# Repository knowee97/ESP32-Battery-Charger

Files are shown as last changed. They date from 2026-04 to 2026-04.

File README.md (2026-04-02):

# ESP32-Battery-Charger
4-layer PCB design featuring the **ESP32-C3-MINI-1** RISC-V SoC with integrated Li-Po battery management.
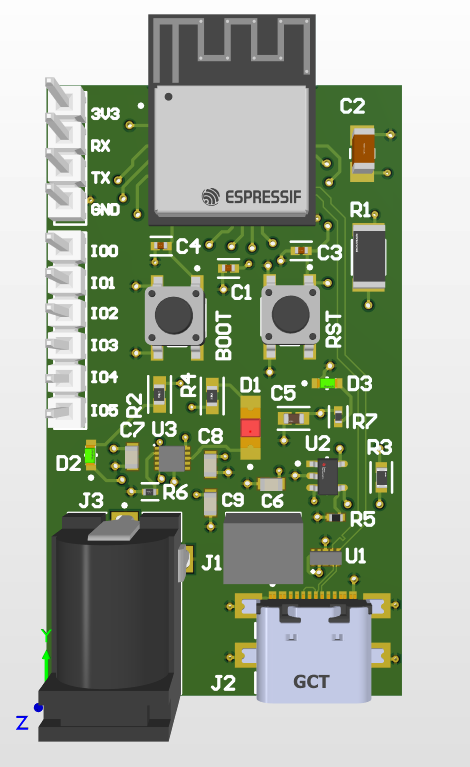
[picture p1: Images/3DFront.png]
ESP32-C3 PCB Render


## 🛠 Technical Specifications
* **Processor**: ESP32-C3-MINI-1 (RISC-V Single-Core, Wi-Fi/Bluetooth LE).
* **Layer Stackup**: 4-Layer (Signal-GND-PWR-Signal) for optimized EMI and Signal Integrity.
* **Power System**: 
    * Integrated Li-Ion Linear Charger with $500\text{mA}$ regulation.
    * USB-C Input with ESD protection and Schottky diode power-path management.
    * Dedicated **CHG** status LED tied to the charging IC.
* **High-Speed Routing**: $90\Omega$ impedance-matched differential pairs for **USB 2.0** data lines.

## 📐 Design & Layout Highlights
* **RF Optimization**: 
    * Implemented a strict 15mm antenna keep-out zone as per the Espressif datasheet.
    * Utilized ground stitching vias to create a low-impedance return path and reduce noise.
* **Thermal Management**: 
    * Designed a $3\times3$ thermal via array on the ESP32 center **EPAD** to dissipate heat into internal ground planes.
* **Manufacturing (DFM)**: 
    * Successfully resolved 50+ Design Rule Violations using targeted clearance exceptions.
    * Maintained 6mil trace/space clearance in high-density areas.

## 🏁 Design Rule Check (DRC)
* **Status**: 0 Errors / 0 Warnings.
* **Custom Rules**: 
    * Implemented `InComponent` queries to allow 1.4mil solder mask slivers on the ESP32 thermal pads while maintaining 10mil global safety clearances.

## 📁 Repository Structure
* `/Hardware`: Altium Designer project files and 3D STEP model.
* `/Manufacturing`: Production-ready Gerber and NC Drill files.
* `/Docs`: Schematic PDF and Bill of Materials (BOM).

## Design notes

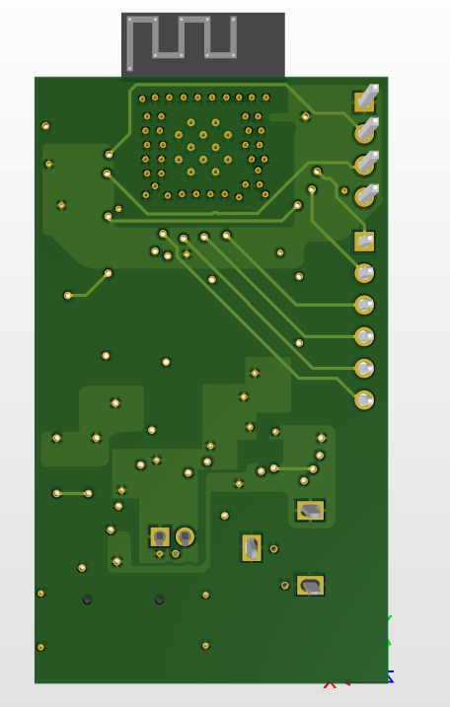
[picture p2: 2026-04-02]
Images/3DBack.png

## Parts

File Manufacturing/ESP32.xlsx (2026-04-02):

Comment | Description | Designator | Footprint | LibRef | Quantity
BOOT | TACT 4.5 X 4.5, 3.8 MM H, 1.8N, | BOOT | FP-PTS647SM38SMTR2LFS-MFG | CMP-10040-000031-1 | 1
HMK105B7103MVHFE | None | C1, C3, C4 | FP-0402-L_1_0_0_05-W_0_5-IPC_A | CMP-14477-001757-2 | 3
LMK316AB7106ML-T | None | C2 | FP-1206-L_3_2_0_2-W_1_6_0-IPC_A | CMP-14477-003406-2 | 1
GRM188Z71A106KA73J | Chip Multilayer Ceramic Capacitors for General Purpose, 0603, 10uF, X7R, 15%, 10%, 10V | C5 | FP-GRM188-0_2-IPC_B | CMP-06035-020296-1 | 1
C0603C105K4RACTU |  | C6, C7, C8, C9 | CAPC1608X90X35LL15T15 | CMP-2006-02298-2 | 4
LTST-C230EKT | LED RED CLEAR CHIP SMD | D1 | FP-LTST-C230EKT-MFG | CMP-22017-000030-1 | 1
APT1608ZGCK | LED GREEN CLEAR CHIP SMD | D2, D3 | FP-APT1608ZGCK-MFG | CMP-44529-000024-1 | 2
B2B-PH-K-S(LF)(SN) | Male Header, Pitch 2 mm, 1 x 2 Position, Height 6 mm, Tail Length 3.4 mm, -25 to 85 degC, RoHS, Bulk | J1 | JST-B2B-PH-K-S_V | CMP-2000-05162-1 | 1
USB4110-GF-A | CONN USB 2.0 TYPE-C R/A SMT | J2 | FP-USB4110-GF-A-MFG | CMP-245163-000002-1 | 1
PJ-102BH | Through Hole Right Angle DC Power Jack, 5 A, 2.5 mm Center Pin, 3 Position, -25 to 85 degC, RoHS, Bulk | J3 | CUI-PJ-102BH_V | CMP-2000-06901-1 | 1
ESP32-C3-MINI-1-N4 | Multiprotocol Modules SMD module, ESP32-C3FN4, PCB antenna, -40 C +85 C | MD1 | FP-ESP32-C3-MINI-1-N4-MFG | CMP-10700-116589975-1 | 1
TSW-104-08-G-S | 0.025" SQ Post Header, Through-hole, Vertical, -55 to 125 degC, 2.54 mm Pitch, 4-Pin, Male, RoHS | P1 | SMTC-TSW-104-08-X-S | CMP-1024-00357-1 | 1
TSW-106-23-G-S | 0.025" SQ Post Header, Through-hole, Vertical, -55 to 125 degC, 2.54 mm Pitch, 6-Pin, Male, RoHS | P2 | SMTC-TSW-106-23-X-S | CMP-1024-00396-1 | 1
CR2010-JW-103ELF | Thick Film Chip Resistors 2010 10kΩ 0.5W 5% 200ppm/°C | R1 | FP-CR2010-IPC_C | CMP-07231-003456-1 | 1
RN73R1JTTD1501B25 | 1.5kΩ ±0.1% 0.1W, 1/10W Chip Resistor 0603 (1608 Metric) Moisture Resistant Thin Film | R2, R4 | FP-RN73R1J-IPC_A | CMP-04015-030520-1 | 2
AT0603BRD0740KL | Thin Film Chip Resistors Automotive Grade 40kΩ 0.1% 25ppm/°C 0603 | R3 | FP-AT0603-IPC_B | CMP-03412-038922-1 | 1
ERJ-2RKF2003X | Chip Resistor, 200 KOhm, +/- 1%, 100 mW, -55 to 155 degC, 0402 (1005 Metric), RoHS, Tape and Reel | R5 | RESC1005X40X25NL05T05 | CMP-1011-00768-4 | 1
CRGCQ0402J1K0 | CRGCQ 0402 1K0 5% | R6 | FP-CRGCQ0402-IPC_C | CMP-03211-005510-1 | 1
TFCR0402-16W-E-1001DT | RES Thin Film, 1kΩ, 0.5%, 0.063W, 25ppm/°C, 0402 | R7 | FP-TFCR0402-IPC_A | CMP-250906-247784-1 | 1
RESET | TACT 4.5 X 4.5, 3.8 MM H, 1.8N, | RST | FP-PTS647SM38SMTR2LFS-MFG | CMP-10040-000031-1 | 1
ESD7104MUTAG | Transient Voltage Suppressor, Low Capacitance ESD Protection for High Speed Data, 10-Pin UDFN, Pb-Free, Tape and Reel | U1 | ONSC-UDFN-10-517BB-01_V | CMP-1063-00242-1 | 1
TLV75801PDBVR | IC POWER MANAGEMENT SUPERVISORY | U2 | FP-DBV0005A-IPC_C | CMP-04917-000142-1 | 1
BQ24040DSQR | 800 mA, Single-Input, Single Cell Li-Ion Battery Charger with Auto Start. Vovp=6.6 V, 3.5 V, -40 to 85 degC, 10-pin SON (DSQ), Green (RoHS & no Sb/Br) | U3 | DSQ0010A_V | CMP-0321-00456-2 | 1

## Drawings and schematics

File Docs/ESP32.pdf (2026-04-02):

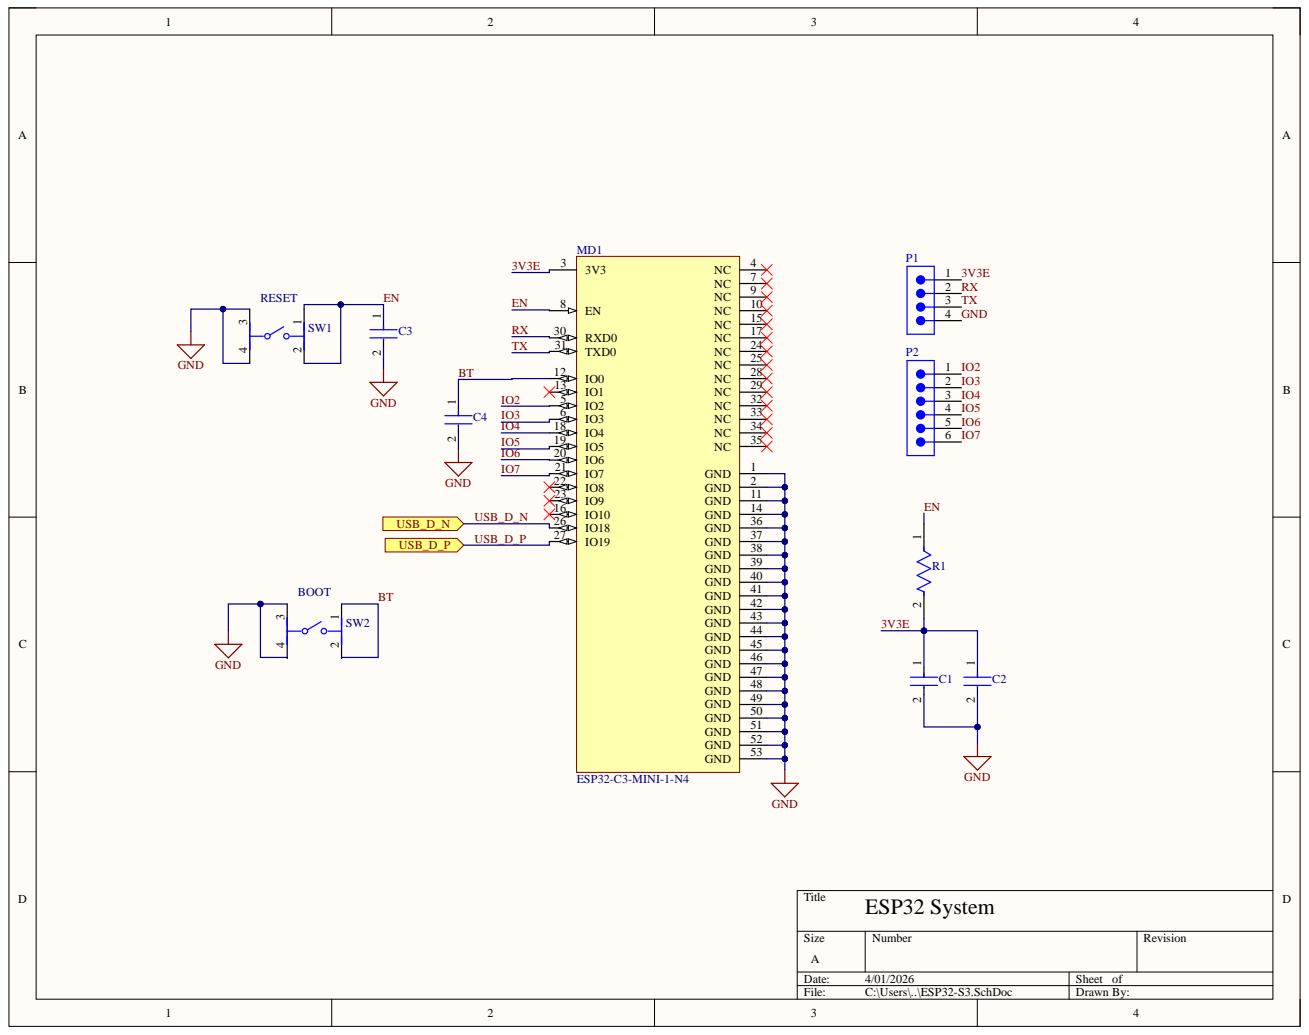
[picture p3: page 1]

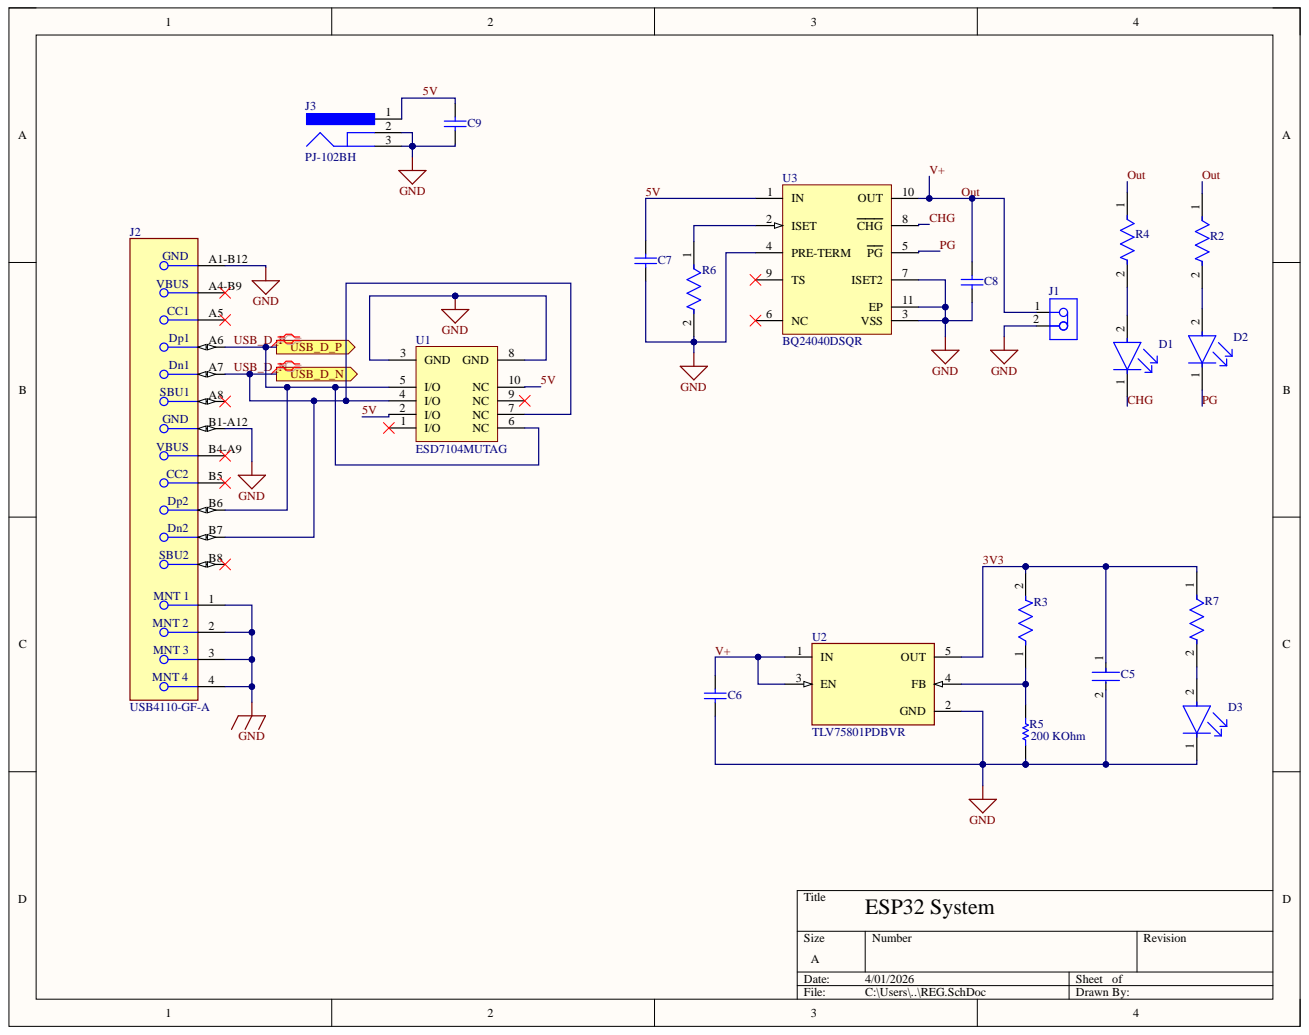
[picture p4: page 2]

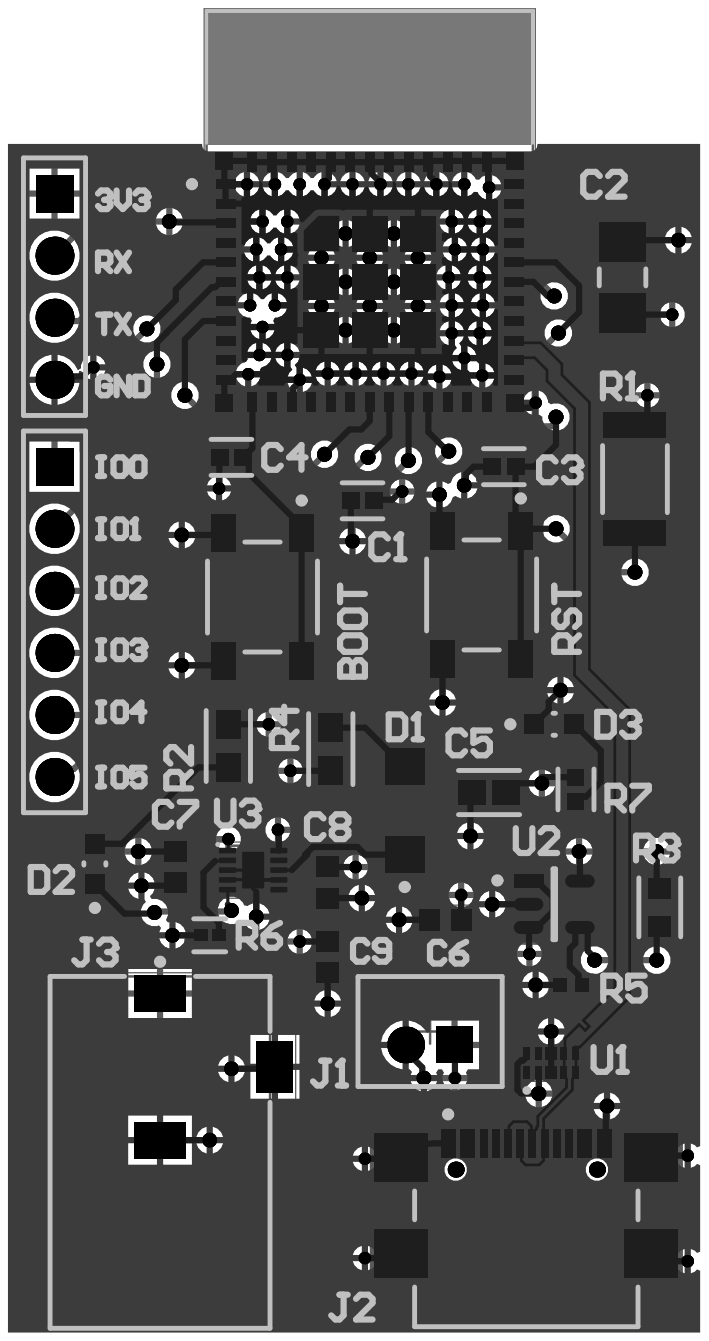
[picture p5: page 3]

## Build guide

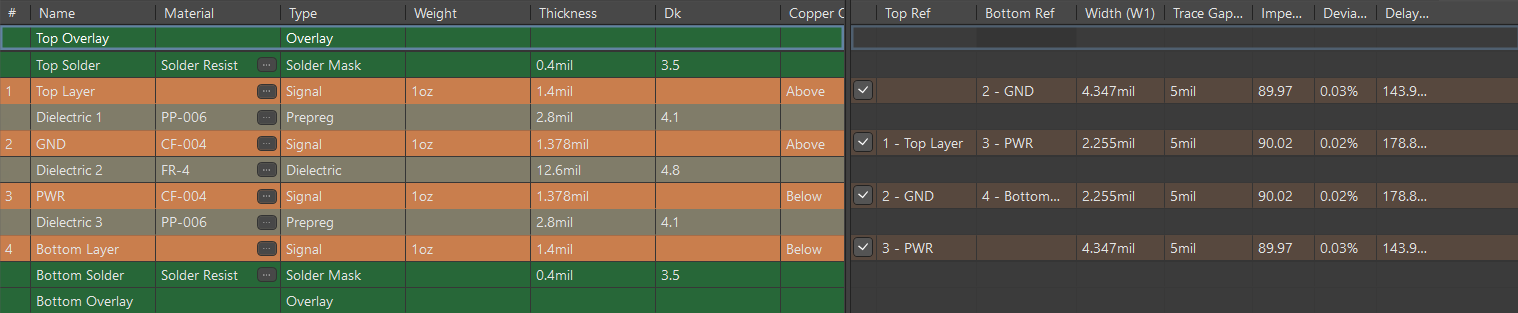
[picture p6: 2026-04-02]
Manufacturing/LayerStackup.png

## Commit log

2026-04-02 Add Hardwaare files via upload
    [ESP32-S3.SchDoc, ESP32.PcbDoc, ESP32.PrjPcb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]
2026-04-02 Added Gerber Files via upload
    [ESP32.GBL, ESP32.GBO, ESP32.GBP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]
